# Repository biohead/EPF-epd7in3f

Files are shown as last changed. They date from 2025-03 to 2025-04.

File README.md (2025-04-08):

# E-paper ESP32 Frame

- **This project is currently a Work in Progress (WIP)!**

This fork adapts for the ACeP 7-colour eInk display - epd7in3f.

This project leverages **Immich** as a service for organizing albums and photos. Photos intended for display are grouped into specific albums, and a FLASK server hosted on a NAS or cloud server handles image cropping and editing before sending them to the ESP32. Since the ESP32 remains in deep sleep most of the time, and all image processing is handled by the server, the EPD updates photos very quickly, typically within 15 seconds. This significantly reduces power consumption.

## Features

- **Captive portal**: By long-pressing setup button on the ESP32 when boot up, the device enters setup mode, allowing the Wi-Fi setup page to store up to five SSIDs. This enhances mobility and makes it easier to switch between networks.
Mostly modifieded from TRMNL WiFiCaptive[https://github.com/usetrmnl/firmware/tree/main/lib/wificaptive]
- **Fully Automated Photo Management**: Manage photos through Immich without additional manual processes; photos will automatically sync to the frame.
- **Ultra-low Power Consumption**: As all image processing and quantization are handled by the server, the device only consumes ~16µA during deep sleep, with photo updates completed within 30 seconds.
- **Customizable Display**: Configure photo orientation, basic color adjustments, album name, and more through the server webpage.
- **Cython impelementation**: Use Cython to significantly accelerate photo processing, achieving up to a 5x speed boost.
- **HTTPS supported**: ESP32 now can connect to secured server.
- **Sleep time impelementation**: ESP32 will enter deep sleep during the specified sleep period.
- **One button**: When the ESP32 is in deep sleep, a short press of the setting button will wake it up and restart the process, while a long press(~5s) of the setting button during boot will enter setting mode.

## Table of Contents

- [Components](#components)
- [Installation](#installation)
- [License](#license)

## Components

- [FireBeetle 2 ESP32-C6](https://www.dfrobot.com/product-2771.html)
- [7.3-inch E Ink ACeP 7-Color E-Paper Display Module + HAT](https://www.waveshare.com/7.3inch-e-paper-hat-f.htm)
- Picture frame: A standard picture frame that accommodates the e-paper frame.
- Li-Po battery with PH2.0 header
- Simple button for wake and setting

## Installation

### Clone the Repository

```bash
$ git clone https://github.com/biohead/epf.git
```

### Manually Build Docker Image

```bash
$ git clone https://github.com/biohead/epf.git
$ docker build -t biohead/epf .
```

### Download Precompiled Docker Image - NOT FOR EPD7IN3F!!!

If you prefer not to build the image yourself, you can download the precompiled image from [DockerHub](https://hub.docker.com/r/jwchen119/epf):

```bash
docker pull jwchen119/epf
```

### Run the Container

Create a container from the image. Don’t forget to edit your Immich API key.

```bash
$ docker run --name epf -e IMMICH-API-KEY='<replace-your-immich-api-key>' -d -p <replace-port>:5000 biohead/epf
```

### Configure `config.yaml` (no longer needed, configure the settings directly from webpage)
<details>
Below is an example of a configured `config.yaml` file:

```yaml
immich:
  # Album name, must match the album name created in Immich
  album: testAlbme
  # Photo rotation angle, accepts only (0, 90, 180, 270)
  rotation: 270
  # Immich server URL
  url: http://192.168.100.36:2283
  # Color(Saturation) enhancement level using PIL's ImageEnhance.Color (1.0 = original level)
  enhanced: 1.5
  # Contrast level using PIL's ImageEnhance.Contrast (1.0 = original level)
  contrast: 1.2
```
</details>

### ESP32-C6

Connect the EPD, ESP32-C6, Li-Po battery, and setting button according to the correct wiring configuration. 
To run the code follow the following steps:

1. Install and set up Arduino IDE
2. Connect your ESP32-C6
3. Rename the Arduino folder from the repo to `epd7in3f`
4. Open the `epd7in3f.ino` file
5. Install following libraries from Arduino library manager:
  5-1. Arduinojson
  5-2. Async TCP
  5-3. ESP Async Web Server
6. Click 'Upload'
7. Connect to the Wifi AP created by the ESP32, named `ESP32_ePAPER`
8. A captive portal shows up allowing to enter your WiFi details and details of the Docker container (e.g. http://192.168.100.10:15151)

You can re-enter the configuration page later by short-circuiting the setting button at least 5 second while rebooting.

## License

This project is licensed under the MIT License.

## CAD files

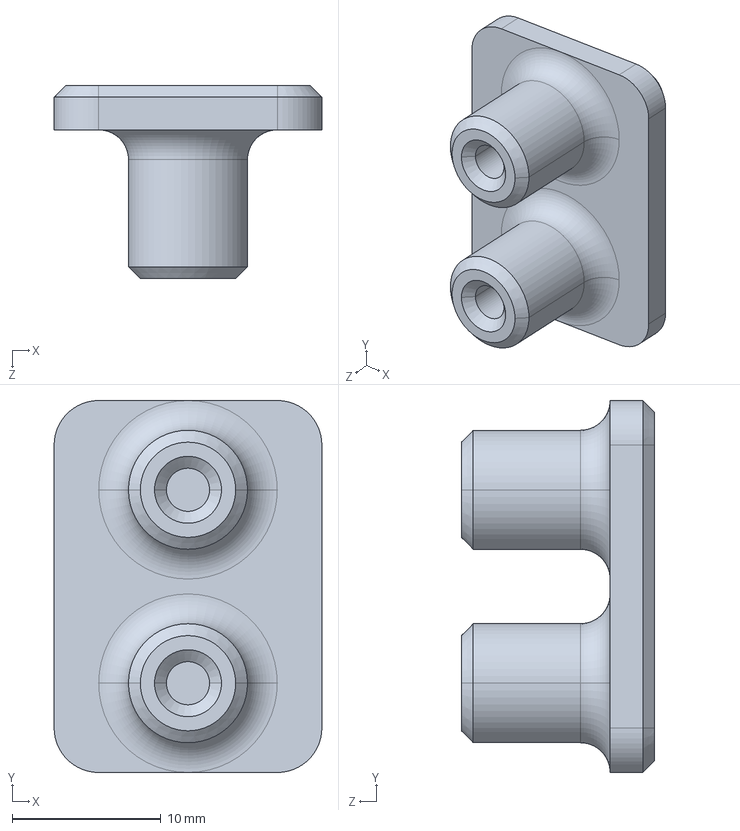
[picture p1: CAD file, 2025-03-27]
CAD/pcb_holder.STEP
18.0 x 25.0 x 13.0 mm

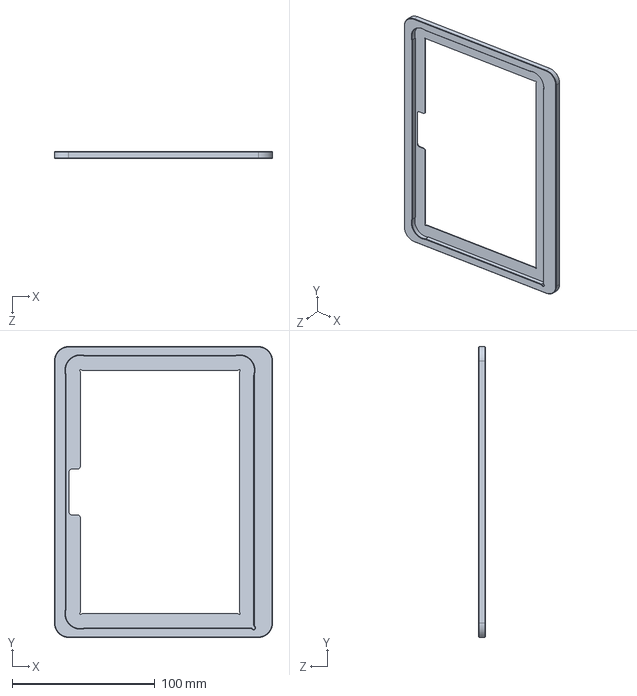
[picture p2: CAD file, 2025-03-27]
CAD/bottom_panel.STEP
152.8 x 203.8 x 5.00 mm

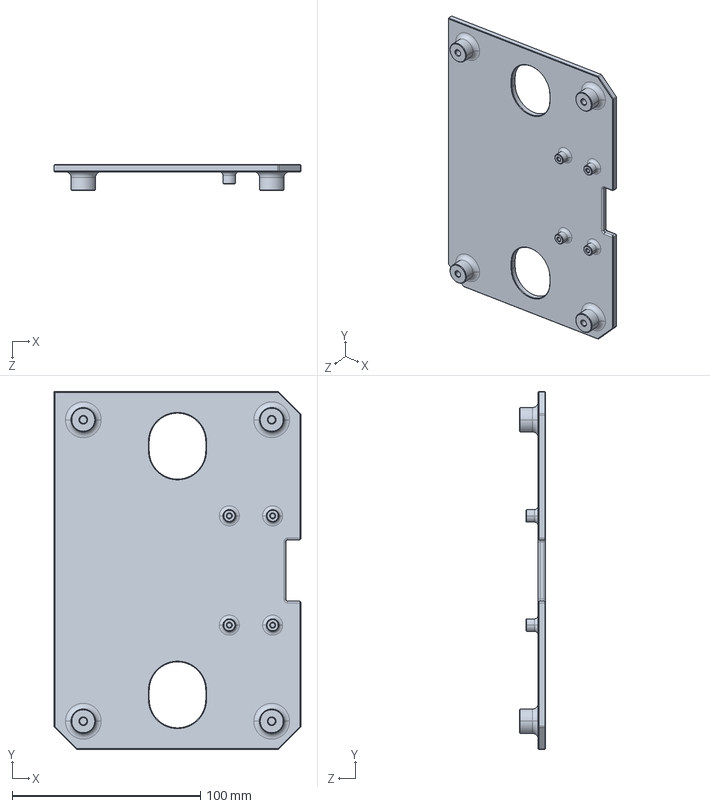
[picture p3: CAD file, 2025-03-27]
CAD/display_holder.STEP
131.0 x 190.0 x 14.0 mm

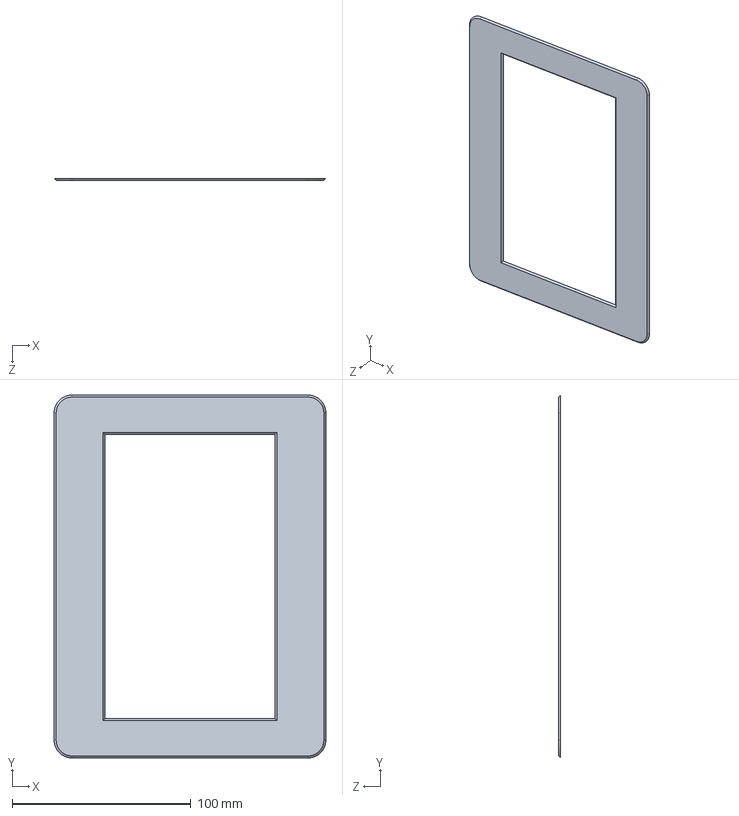
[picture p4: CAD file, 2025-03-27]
CAD/display_card.STEP
152.2 x 203.2 x 1.20 mm

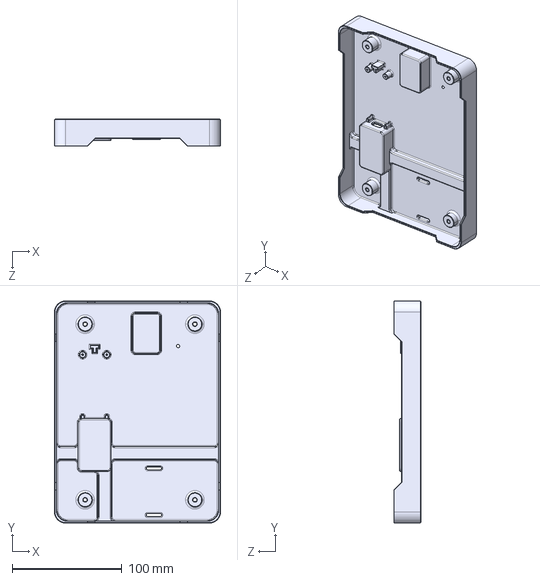
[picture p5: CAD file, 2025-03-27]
CAD/upper_panel.STEP
151.2 x 202.2 x 25.0 mm

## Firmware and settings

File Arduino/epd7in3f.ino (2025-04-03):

#include <Arduino.h>
#include <SPI.h>
#include <HTTPClient.h>
#include "epd7in3f.h"
#include "FS.h"
#include <ArduinoJson.h>
// #include "SimpleWiFiManager.h"
#include <WiFiClientSecure.h>
#include "driver/rtc_io.h"
#include "config.h"
#include "button.h"
#include <Preferences.h>
#include <WifiCaptive.h>
#include <filesystem.h>

/* Pin Layout Description
DRIVER BOARD  <>  FireBeetle ESP32-C6
BUSY          <>  18  // E-paper busy signal input
RST           <>  14  // E-paper reset control
DC            <>  8   // Data/Command control
CS            <>  1   // Chip select control
SCLK          <>  23  // SPI clock
DIN           <>  22  // SPI data input
GND           <>  GND // Ground
VCC           <>  3V3 // Power supply
SETTING       <>  2  // Configuration mode trigger pin
*/

Preferences preferences;

class EpaperManager
{
private:
  // SimpleWiFiManager wifiManager;
  Epd epd;
  String imageUrl = "";

  bool downloadImage()
  {
    // preferences.begin("data, true");
    imageUrl = preferences.getString("SERVER_BASE_URL");
    Serial.print("nas url: ");
    Serial.println(imageUrl);
    bool isHttps = imageUrl.startsWith("https://");
    WiFiClient *basicClient = nullptr;
    WiFiClientSecure *secureClient = nullptr;
    HTTPClient http;
    HTTPClient sleepHttp; // New HTTP client for sleep request
    http.setTimeout(HTTP_TIMEOUT);

    // Parse base URL for sleep request
    String baseUrl = imageUrl;
    const char *downloadPath = "/download";
    const char *sleepPath = "/sleep";

    String sleepUrl = baseUrl + sleepPath;

    // Setup client for image download
    if (isHttps)
    {
      secureClient = new WiFiClientSecure;
      secureClient->setInsecure();
      if (!http.begin(*secureClient, imageUrl + downloadPath))
      {
        Serial.println("Failed to initialize HTTPS connection");
        delete secureClient;
        return false;
      }
    }
    else
    {
      basicClient = new WiFiClient;
      if (!http.begin(*basicClient, imageUrl + downloadPath))
      {
        Serial.println("Failed to initialize HTTP connection");
        delete basicClient;
        return false;
      }
    }

    // Add battery voltage to header
    analogReadResolution(12);
    int plusV = 0;
    for (int i = 0; i < 50; i++)
    {
      plusV += analogReadMilliVolts(0);
      delay(5);
    }
    int batteryVoltage = (plusV / 50) * 2;
    http.addHeader("batteryCap", String(batteryVoltage));

    // Download and process image
    bool success = false;
    int sleepDuration = 0;
    bool retryOnError = true; // Add retry flag

    while (retryOnError && !success)
    {                       // Add retry loop
      retryOnError = false; // Default to no retry

      for (uint8_t i = 0; i < MAX_RETRIES; i++)
      {
        int httpCode = http.GET();

        if (httpCode == HTTP_CODE_OK)
        {
          success = processImageData(&http);

          // After successful image download, get sleep duration
          if (success)
          {
            // Setup new client for sleep request
            WiFiClient *sleepBasicClient = nullptr;
            WiFiClientSecure *sleepSecureClient = nullptr;

            if (isHttps)
            {
              sleepSecureClient = new WiFiClientSecure;
              sleepSecureClient->setInsecure();
              sleepHttp.begin(*sleepSecureClient, sleepUrl);
            }
            else
            {
              sleepBasicClient = new WiFiClient;
              sleepHttp.begin(*sleepBasicClient, sleepUrl);
            }

            sleepHttp.addHeader("Accept", "application/json");
            int sleepHttpCode = sleepHttp.GET();

            if (sleepHttpCode == HTTP_CODE_OK)
            {
              String payload = sleepHttp.getString();
              StaticJsonDocument<200> doc;
              DeserializationError error = deserializeJson(doc, payload);

              if (!error)
              {
                sleepDuration = doc["sleep_duration"] | 0;
                if (sleepDuration > 0)
                {
                  sleepDuration /= 1000; // Convert to seconds
                }
              }
            }

            sleepHttp.end();
            if (sleepSecureClient)
              delete sleepSecureClient;
            if (sleepBasicClient)
              delete sleepBasicClient;
          }
          break;
        }
        else if (httpCode == HTTP_CODE_ACCEPTED)
        {
          Serial.println("Server processing, waiting...");
          delay(RETRY_DELAY);
        }
        else if (httpCode == HTTP_CODE_INTERNAL_SERVER_ERROR)
        {
          Serial.println("Server error (500), will retry once...");
          delay(RETRY_DELAY);
          retryOnError = true; // Enable one retry on 500 error
          break;               // Exit current retry loop
        }
        else
        {
          Serial.printf("%s GET failed: %s\n",
                        isHttps ? "HTTPS" : "HTTP",
                        http.errorToString(httpCode).c_str());
          break;
        }
      }
    }

    http.end();
    delay(10);
    if (secureClient)
      delete secureClient;
    if (basicClient)
      delete basicClient;

    // If we got a valid sleep duration, use it for hibernation
    if (success && sleepDuration > 0)
    {
      hibernate(sleepDuration);
    }
    else
    {
      // Use default sleep duration if server didn't provide one
      hibernate();
    }

    return success;
  }

  // check if https
  bool startsWith(const String &str, const char *prefix)
  {
    return str.substring(0, strlen(prefix)).equalsIgnoreCase(prefix);
  }

  // Checks if character is a valid delimiter in image data
  bool isDelimiter(char c)
  {
    return c == ',' || c == '\n' || c == '\r' || c == '\0';
  }

  // Process image data stream and update display
  bool processImageData(HTTPClient *http)
  {
    WiFiClient *stream = http->getStreamPtr();
    int contentLength = http->getSize();

    // Validate content length
    if (contentLength <= 0)
    {
      Serial.println("Invalid content length");
      return false;
    }
    Serial.printf("Content-Length: %d bytes\n", contentLength);
    Serial.println("Starting direct image processing...");

    epd.SendCommand(0x10);

    uint8_t *buffer = (uint8_t *)malloc(BUFFER_SIZE);
    if (buffer == NULL)
    {
      Serial.println("Buffer allocation failed");
      return false;
    }

    String hexBuffer;
    int totalBytesProcessed = 0;

    while (contentLength > 0 && http->connected())
    {
      int bytesToRead = min(contentLength, (int)sizeof(buffer));
      int bytesRead = stream->readBytes(buffer, bytesToRead);

      if (bytesRead > 0)
      {
        for (int i = 0; i < bytesRead; i++)
        {
          char c = (char)buffer[i];
          if (isDelimiter(c))
          {
            if (!hexBuffer.isEmpty())
            {
              uint8_t byteValue = (uint8_t)strtol(hexBuffer.c_str(), nullptr, 16);
              epd.SendData(byteValue);
              hexBuffer.clear();
            }
          }
          else
          {
            hexBuffer += c;
          }
        }

        totalBytesProcessed += bytesRead;
        contentLength -= bytesRead;
      }
      else
      {
        if (!http->connected())
        {
          Serial.println("HTTP connection lost!");
          free(buffer);
          return false;
        }
        delay(10);
      }
    }

    if (!hexBuffer.isEmpty())
    {
      uint8_t byteValue = (uint8_t)strtol(hexBuffer.c_str(), nullptr, 16);
      epd.SendData(byteValue);
    }

    free(buffer);
    Serial.println("Showing image");
    epd.TurnOnDisplay();
    epd.Sleep();

    return true;
  }

  // Enter deep sleep mode with calculated wake-up interval
  void hibernate(int sleepDuration = 0)
  {
    Serial.println("Preparing for deep sleep...");

    // Use provided sleep duration or get default from WiFi manager
    // int sleep_interval = sleepDuration > 0 ? sleepDuration : wifiManager.getServerSleepDuration();
    int sleep_interval = sleepDuration > 0 ? sleepDuration : 86400;

    // Disconnect WiFi and turn off radio
    WiFi.disconnect(true);
    WiFi.mode(WIFI_OFF);
    fs_deinit();
    delay(50);
    // Print sleep duration for debugging
    Serial.printf("Sleep interval: %d seconds\n", sleep_interval);

    // Convert sleep time to microseconds
    uint64_t sleep_time;
    if (sleep_interval > 0)
    {
      sleep_time = static_cast<uint64_t>(sleep_interval) * 1000000ULL;
    }
    else
    {
      sleep_time = static_cast<uint64_t>(SLEEP_INTERVAL) * 1000000ULL;
    }

    Serial.printf("Sleep time in microseconds: %llu\n", sleep_time);

    // Configure wake up sources
    esp_sleep_enable_timer_wakeup(sleep_time);

    // Configure GPIO wake up
    rtc_gpio_init(WAKEUP_PIN);
    rtc_gpio_set_direction(WAKEUP_PIN, RTC_GPIO_MODE_INPUT_ONLY);
    rtc_gpio_pullup_en(WAKEUP_PIN);
    rtc_gpio_pulldown_dis(WAKEUP_PIN);
    esp_sleep_enable_ext1_wakeup(1ULL << WAKEUP_PIN, ESP_EXT1_WAKEUP_ANY_LOW);

    // Wait for serial output to complete
    Serial.println("Entering deep sleep mode...");
    Serial.flush();

    // Add delay before sleep
    delay(50);

    // Enter deep sleep
    esp_deep_sleep_start();
  }

  static void resetDeviceCredentials(void)
  {
    WifiCaptivePortal.resetSettings();
    bool res = preferences.clear();
    preferences.end();
    ESP.restart();
  }

  // Check if configuration mode should be entered
  bool shouldEnterConfigMode()
  {
    // Check configuration pin with debounce
    // if (digitalRead(CONFIG_PIN) == LOW) {
    //   delay(BUTTON_DEBOUNCE);
    //   return digitalRead(CONFIG_PIN) == LOW;
    // }
    // return false;
    Button button(CONFIG_PIN);
    return button.result();
  }

public:
  bool begin()
  {
    Serial.begin(115200);
    delay(50);
    pinMode(CONFIG_PIN, INPUT_PULLUP);

    if (epd.Init() != 0)
    {
      Serial.println(F("e-Paper init failed"));
      return false;
    }
    Serial.println(F("e-Paper initialized successfully"));

    // initialize spiffs
    fs_init();

    // initialize preferences
    preferences.begin("data", true);

    WiFi.mode(WIFI_STA);

    // Check configuration button
    if (shouldEnterConfigMode())
    {
      Serial.println(F("Config button pressed, entering config mode..."));
      epd.Clear(EPD_7IN3F_WHITE);
      // epd.Sleep();

      bool res = WifiCaptivePortal.startPortal();
      if (res)
      {
        Serial.println(F("Config mode completed"));
        return true;
      }
      // else {
      //   epd.Clear(EPD_7IN3F_WHITE);
      //   epd.Sleep();
      //   return false;
      // }
    }

    // If button not pressed, try normal startup
    if (WifiCaptivePortal.isSaved())
    {
      int connection_res = WifiCaptivePortal.autoConnect();
      if (connection_res)
      {
        preferences.putInt(PREFERENCES_CONNECT_WIFI_RETRY_COUNT, 1);
        return true;
      }
      // else {
      //   epd.Clear(EPD_7IN3F_WHITE);
      //   epd.Sleep();
      // }
    }
    else
    {
      WifiCaptivePortal.setResetSettingsCallback(resetDeviceCredentials);
      bool res = WifiCaptivePortal.startPortal();
      if (res)
      {
        preferences.putInt(PREFERENCES_CONNECT_WIFI_RETRY_COUNT, 1);
        return true;
      }
      //   if (!res) {
      //     epd.Clear(EPD_7IN3F_WHITE);
      //     epd.Sleep();
    }
    // }
    Serial.println(F("No valid WiFi configuration found - main"));
    return false;
  }

  void update()
  {
    Serial.println(F("Update method called"));

    if (WiFi.status() == WL_CONNECTED)
    {
      Serial.println(F("WiFi Connected. Downloading image"));
      if (downloadImage())
      {
        Serial.println(F("Image download successful"));
      }
      else
      {
        Serial.println(F("Image download failed"));
      }
    }
    else
    {
      Serial.println(F("WiFi not connected. Cannot download image"));
    }

    Serial.println(F("Entering sleep mode"));
    hibernate();
  }

  // Check battery voltage level
  bool checkVoltage()
  {
    analogReadResolution(12);
    int analogVolts = analogReadMilliVolts(0);
    // Multiply by 2 due to voltage divider
    Serial.print("BAT millivolts value = ");
    Serial.print(analogVolts * 2);
    Serial.println("mV");
    delay(50);
    // Return false if battery voltage is below 3.05V
    if (analogVolts * 2 < 3050)
    {
      return false;
    }
    return true;
  }

  // Clear the e-paper display
  void clearScreen()
  {
    epd.Init();
    delay(1000);
    epd.Clear(EPD_7IN3F_WHITE);
    epd.Sleep();
  }
};

// Global instance
EpaperManager epaperManager;

void setup()
{
  // Determine wake up reason
  esp_sleep_wakeup_cause_t wakeup_reason = esp_sleep_get_wakeup_cause();

  if (wakeup_reason == ESP_SLEEP_WAKEUP_TIMER)
  {
    Serial.println("Wakeup caused by timer");
  }
  else if (wakeup_reason == ESP_SLEEP_WAKEUP_EXT1)
  {
    Serial.println("Wakeup caused by external signal using RTC_GPIO");
  }
  else
  {
    Serial.println("First boot or reset");
  }

  if (!epaperManager.checkVoltage())
  {
    Serial.println(F("Battery low voltage (< 3.0V)"));
    Serial.println(F("Sleep for 24hr"));
    epaperManager.clearScreen();
    WiFi.disconnect(true);
    WiFi.mode(WIFI_OFF);
    delay(1000);
    esp_sleep_enable_timer_wakeup(86400 * 1000000ULL);
    esp_deep_sleep_start();
  }
  if (epaperManager.begin())
  {
    Serial.println(F("Begin successful, calling update"));
    epaperManager.update();
  }
  else
  {
    Serial.println(F("Begin failed"));
    epaperManager.clearScreen();

    delay(30000);
    ESP.restart();
  }
}

void loop()
{
  // deepsleep
}

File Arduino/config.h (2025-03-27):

#ifndef CONFIG_H
#define CONFIG_H

// File system configuration
// #define CONFIG_FILE "/wifi_config.json"

// WiFi and HTTP configuration
#define HTTP_TIMEOUT 50000U // HTTP request timeout in ms
#define RETRY_DELAY 10000U  // Delay between retries in ms
#define MAX_RETRIES 5U      // Maximum number of retry attempts

// GPIO Configuration
#define CONFIG_PIN 2U          // Configuration mode trigger pin
#define BUTTON_DEBOUNCE 100U   // Button debounce time in ms
#define BUTTON_HOLD_TIME 3000U // Button hold time in ms

// Sleep and timing configuration
#define SLEEP_TIME_COMPENSATION 1.009f // Sleep time compensation factor
#define SLEEP_INTERVAL 3600U           // Default sleep interval in seconds (1 hour)
#define MIN_SLEEP_TIME 900U            // Minimum sleep time in seconds (15 minutes)

// Wake up source configuration
#define WAKEUP_PIN GPIO_NUM_2                 // GPIO 2 for wake up
#define WAKEUP_LEVEL ESP_GPIO_WAKEUP_GPIO_LOW // Wake up on low level

// Buffer configuration
#define BUFFER_SIZE 131072U // Buffer size for image processing

#define SERVER_BASE_URL "http://server.ip:15001"
#define PREFERENCES_SLEEP_TIME_KEY "refresh_rate"
#define PREFERENCES_LAST_SLEEP_TIME "last_sleep"
#define PREFERENCES_CONNECT_API_RETRY_COUNT "retry_count"
#define PREFERENCES_CONNECT_WIFI_RETRY_COUNT "wifi_retry"

#define CONFIG_TIMEOUT 300000U // 5 minute

#endif // CONFIG_H

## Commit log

2025-03-27 upload cad files
    [bottom_panel.STEP, display_card.STEP, display_holder.STEP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]
2025-04-07 Additional changes missed on initial commit
    [epd7in3f.cpp]
